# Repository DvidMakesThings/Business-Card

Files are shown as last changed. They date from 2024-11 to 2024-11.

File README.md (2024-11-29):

# Business_Card_LA Project

Business_Card_LA is a unique project where a business card doubles as a logic analyzer. It is designed based on Cypress CY7C68013A USB controller. It can sample 8 channels at the same time. The maximum sampling rate of each channel is 24Mhz, and the maximum logical level supports 5.5V. The software adopts sigrok-PulseView, which is open source, and supports Linux, Windows, Mac OS X and other platforms. It supports more than 100 kinds of protocol analysis, and can add its own protocol analysis.

## Specifications
- **Sampling rate and number of channels**: 24Mhz, 8 Channel
- **Signal input range**: 0-5.5V
- **High and low level recognition range**: Vin High: >2V, Vin Low: <0.8V
- **Communication mode**: USB 2.0 (In order to ensure the sampling rate of 24Mhz, try not to use USB docking station)

## Usage
1. **Download sigrok-PulseView Software**: Be sure to download the Release build from [sigrok Downloads](https://sigrok.org/wiki/Downloads).
2. **Install sigrok-PulseView & LogicAnalyzer driver**:
   - After PulseView is installed, run Zadig from the installation folder: `\sigrok\PulseView\zadig.exe`.
   - Select the device you want to install the driver on. The business card appears as Unknown device with VID/PID 04B4:8613.
   - Check Edit, change the device name to fx2LAFw, and then click Install Driver.
3. **Run PulseView**:
   - Click PulseView to run the software.
   - The status LED will light up and it's blue, indicating that the firmware is loaded successfully and the logic signal can be sampled.

## Supported Protocols
See [sigrok Supported Protocol decoders](https://sigrok.org/wiki/Protocol_decoders).

## License
This project is licensed under the GPL-3.0 License.

## Contact
For any questions or feedback, please contact:
- Email: [s.dvid@hotmail.com](mailto:s.dvid@hotmail.com)
- GitHub: [DvidMakesThings](https://github.com/DvidMakesThings)

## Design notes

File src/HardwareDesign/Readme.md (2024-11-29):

# # Business_Card_LA Project Hardware Design Files

## Contents
This folder contains the hardware design files for the Business_Card_LA project. The main components include:
- Schematic diagrams
- PCB layouts
- Bill of Materials (BOM)
- Gerber files

## Usage
To use these hardware design files:
1. Open the schematic diagrams and PCB layouts using EAGLE software.
2. Review the Bill of Materials for required components.
3. Follow the design files to assemble and test the hardware.
4. Use the Gerber files for PCB manufacturing.

## License
This project is licensed under the MIT License.

## Contact
For any questions or feedback, please contact:
- Email: [s.dvid@hotmail.com](mailto:s.dvid@hotmail.com)
- GitHub: [DvidMakesThings](https://github.com/DvidMakesThings)

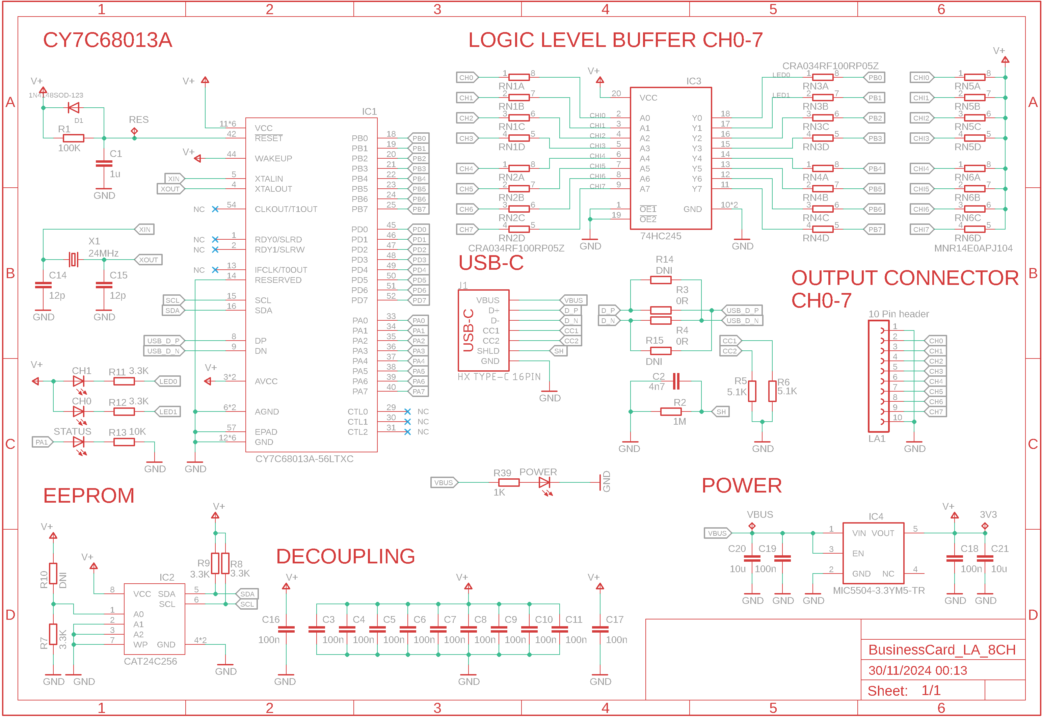
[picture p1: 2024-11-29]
images/schematics.png

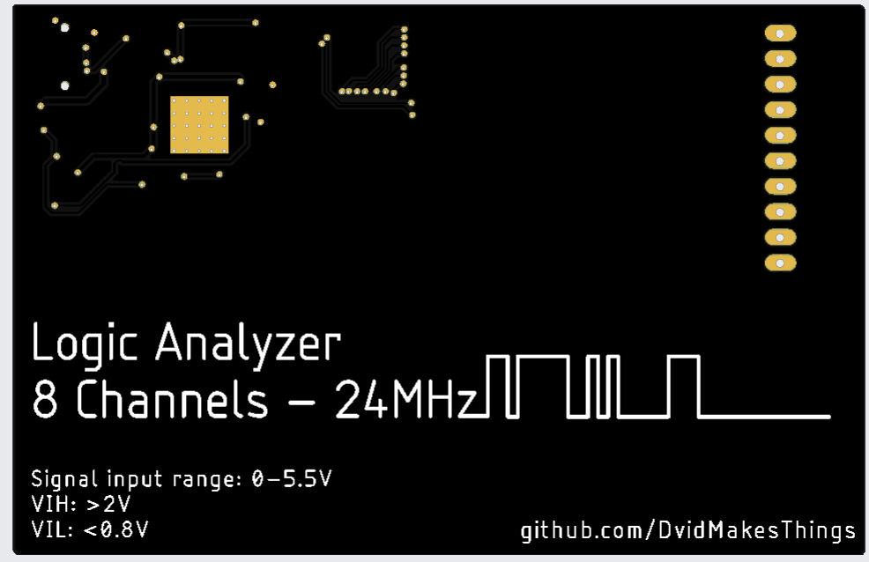
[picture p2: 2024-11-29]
images/PCB_Bottom.png

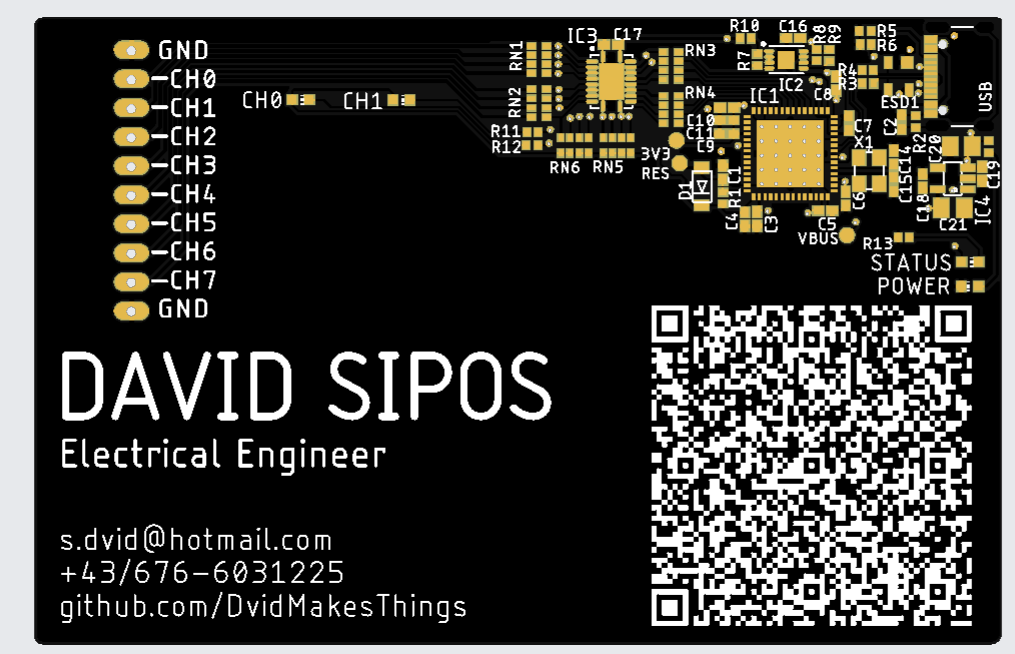
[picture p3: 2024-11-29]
images/PCB_Top.png

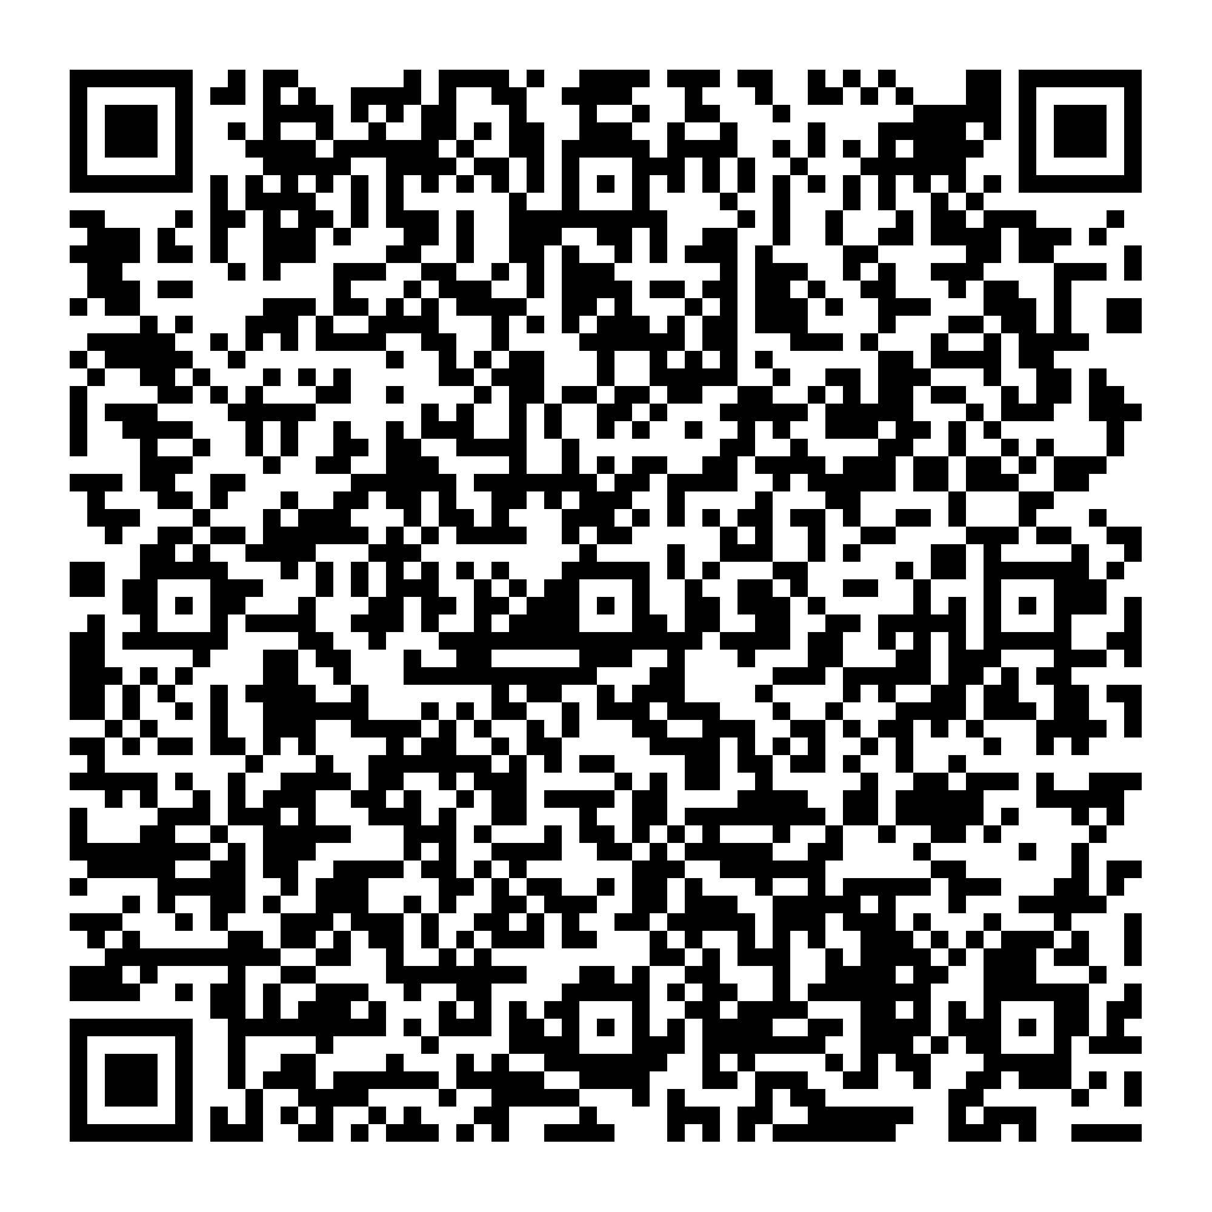
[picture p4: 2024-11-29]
images/qr_vcard.png

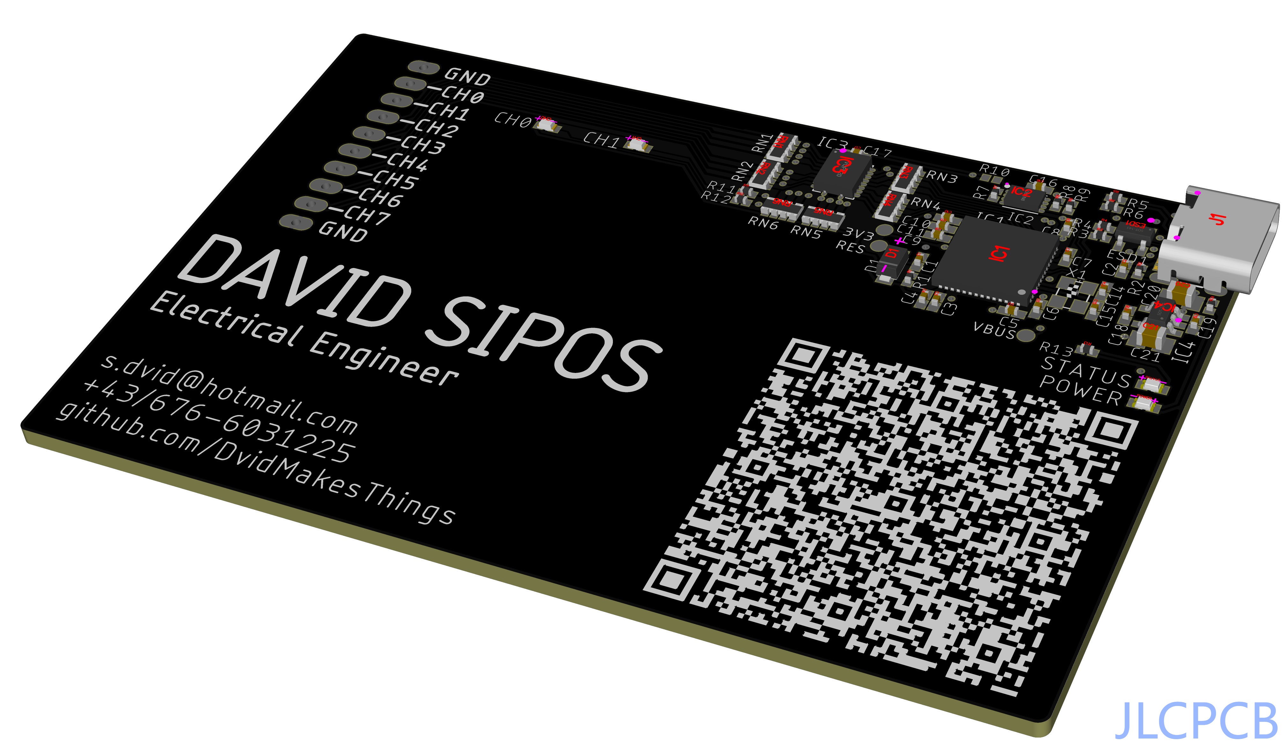
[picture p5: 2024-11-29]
images/capture-2024-11-15T15_52_39.032Z.jpg

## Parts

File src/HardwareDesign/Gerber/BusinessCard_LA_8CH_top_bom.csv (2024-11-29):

Comment | Designator | Footprint | LCSC Part #
 | POWER | CHIP-LED0603
0R | R3 R4 | R0402
1K | R39 | R0402
1M | R2 | R0402
1N4148SOD-123 | D1 | SOD-123FL
1u | C1 | C0402K
3.3K | R7 R8 R9 R11 R12 | R0402
4n7 | C2 | C0402K
5.1K | R5 R6 | R0402
10K | R13 | R0402
10u | C20 C21 | C0805K
12p | C14 C15 | C0402K
19-217/GHC-YR1S2/3T | CH0 CH1 | CHIP-LED0603
24MHz | X1 | 3.2X2.5_KX-7
100K | R1 | R0402
100n | C3 C4 C5 C6 C7 C8 C9 C10 C11 C16 C17 C18 C19 | C0402K
CAT24C256HU4IGT3 | IC2 | SON50P300X200X50-9T130X140N
CRA034RF100RP05Z | RN1 RN2 RN3 RN4 | CAT16
CY7C68013A-56LTXC | IC1 | QFN50P800X800X100-57T665
DNI | R10 | R0402
HX TYPE-C 16PIN | J1 | USB-C-16P-2LAYER-PADS
MIC5504-3.3YM5-TR | IC4 | SOT23-5
MNR14E0APJ104 | RN5 RN6 | CAT16
SN74LVC541ARGYR | IC3 | QFN50P350X450X100-25T305X205N
TPB1 27 | 3V3 | B1 27
TPB1 27 | RES | B1 27
TPB1 27 | VBUS | B1 27
YLED0603B | STATUS | CHIP-LED0603

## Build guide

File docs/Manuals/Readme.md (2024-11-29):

# Business_Card_LA Project Manuals

## Contents
- Manuals

## Usage
This folder contains documentation and manuals for the Business_Card_LA project.

## License
This project is licensed under the MIT License.

## Contact
For any questions or feedback, please contact:
- Email: [s.dvid@hotmail.com](mailto:s.dvid@hotmail.com)
- GitHub: [DvidMakesThings](https://github.com/DvidMakesThings)

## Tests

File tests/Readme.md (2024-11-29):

# Business_Card_LA Project Test files

This folder contains the main test files for the Business_Card_LA project.

## Contents
- Various test scripts and files for the Business_Card_LA project.

## Usage
1. Clone the repository.
2. Navigate to this folder.
3. Run the test scripts as needed.

## License
This project is licensed under the MIT License.

## Contact
For any questions or feedback, please contact:
- Email: [s.dvid@hotmail.com](mailto:s.dvid@hotmail.com)
- GitHub: [DvidMakesThings](https://github.com/DvidMakesThings)

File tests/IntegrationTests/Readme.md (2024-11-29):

# # Business_Card_LA Project Integration Tests

This folder contains integration tests for the Business_Card_LA project.

## Contents

- Various integration test scripts and resources.

## Usage

1. Clone the repository.
2. Navigate to this folder.
3. Run the integration tests using your preferred testing framework.

## License
This project is licensed under the MIT License.

## Contact
For any questions or feedback, please contact:
- Email: [s.dvid@hotmail.com](mailto:s.dvid@hotmail.com)
- GitHub: [DvidMakesThings](https://github.com/DvidMakesThings)

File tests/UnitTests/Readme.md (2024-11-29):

# Business_Card_LA Project Unit Tests

## Contents
This folder contains unit tests for the Business_Card_LA project.

## Usage
To run the unit tests, navigate to this directory and execute the test scripts using your preferred testing framework.

## License
This project is licensed under the MIT License.

## Contact
For any questions or feedback, please contact:
- Email: [s.dvid@hotmail.com](mailto:s.dvid@hotmail.com)
- GitHub: [DvidMakesThings](https://github.com/DvidMakesThings)

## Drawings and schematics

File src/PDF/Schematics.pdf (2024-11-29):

# CY7C68013A

# LOGIC LEVEL BUFFER CH0-7

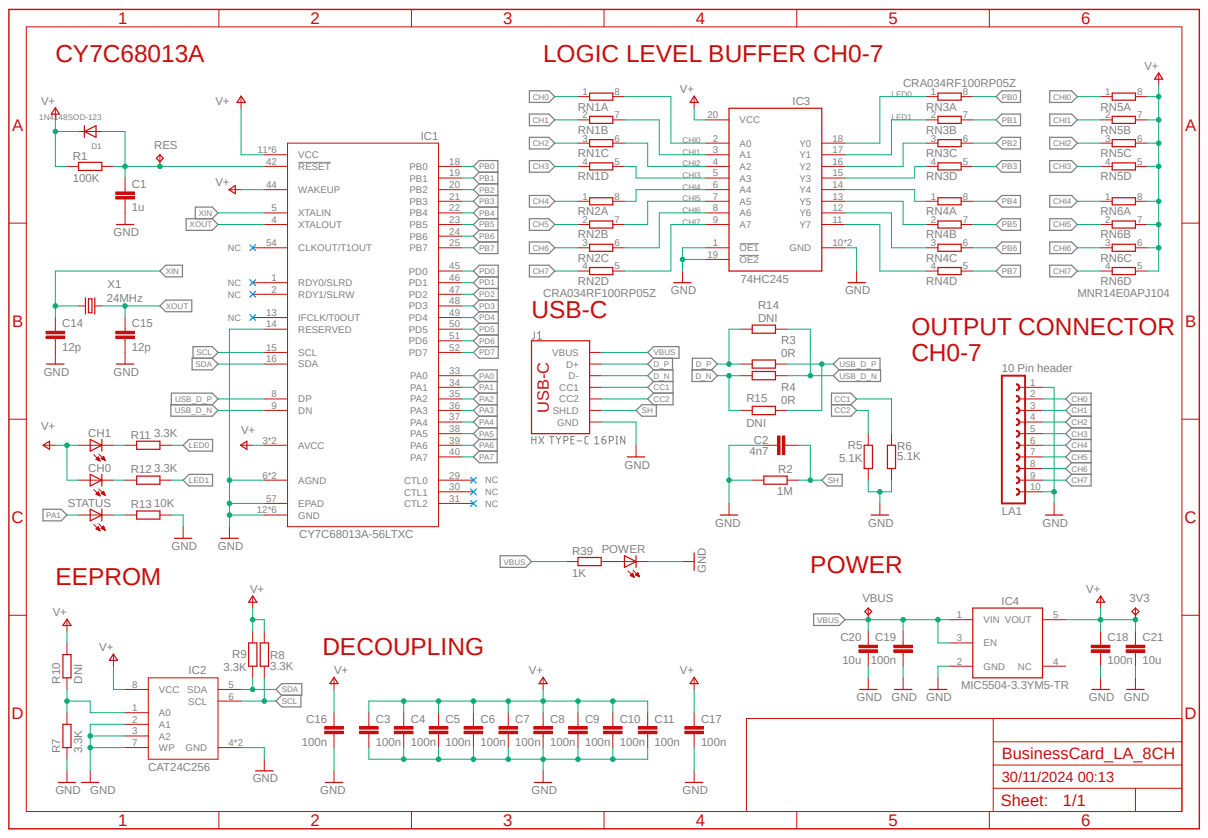
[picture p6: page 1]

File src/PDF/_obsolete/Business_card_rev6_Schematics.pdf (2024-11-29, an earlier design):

A

A

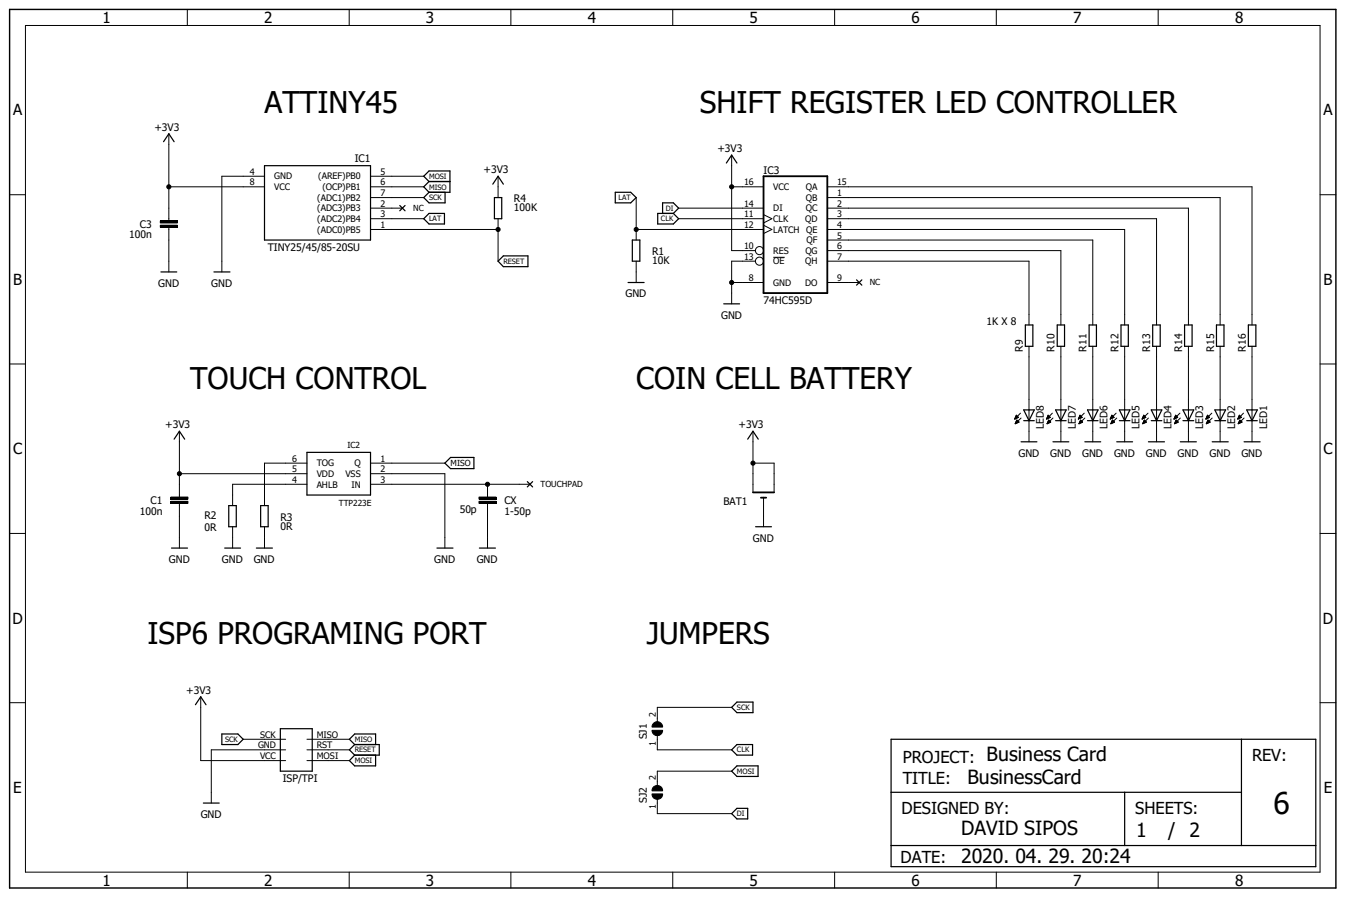
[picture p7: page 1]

SHIFT REGISTER LED CONTROLLER

GND GND GND GND

Business Card PROJECT: BusinessCard TITLE: | REV:

DESIGNED BY: DAVID SIPOS | SHEETS: 1 2 /

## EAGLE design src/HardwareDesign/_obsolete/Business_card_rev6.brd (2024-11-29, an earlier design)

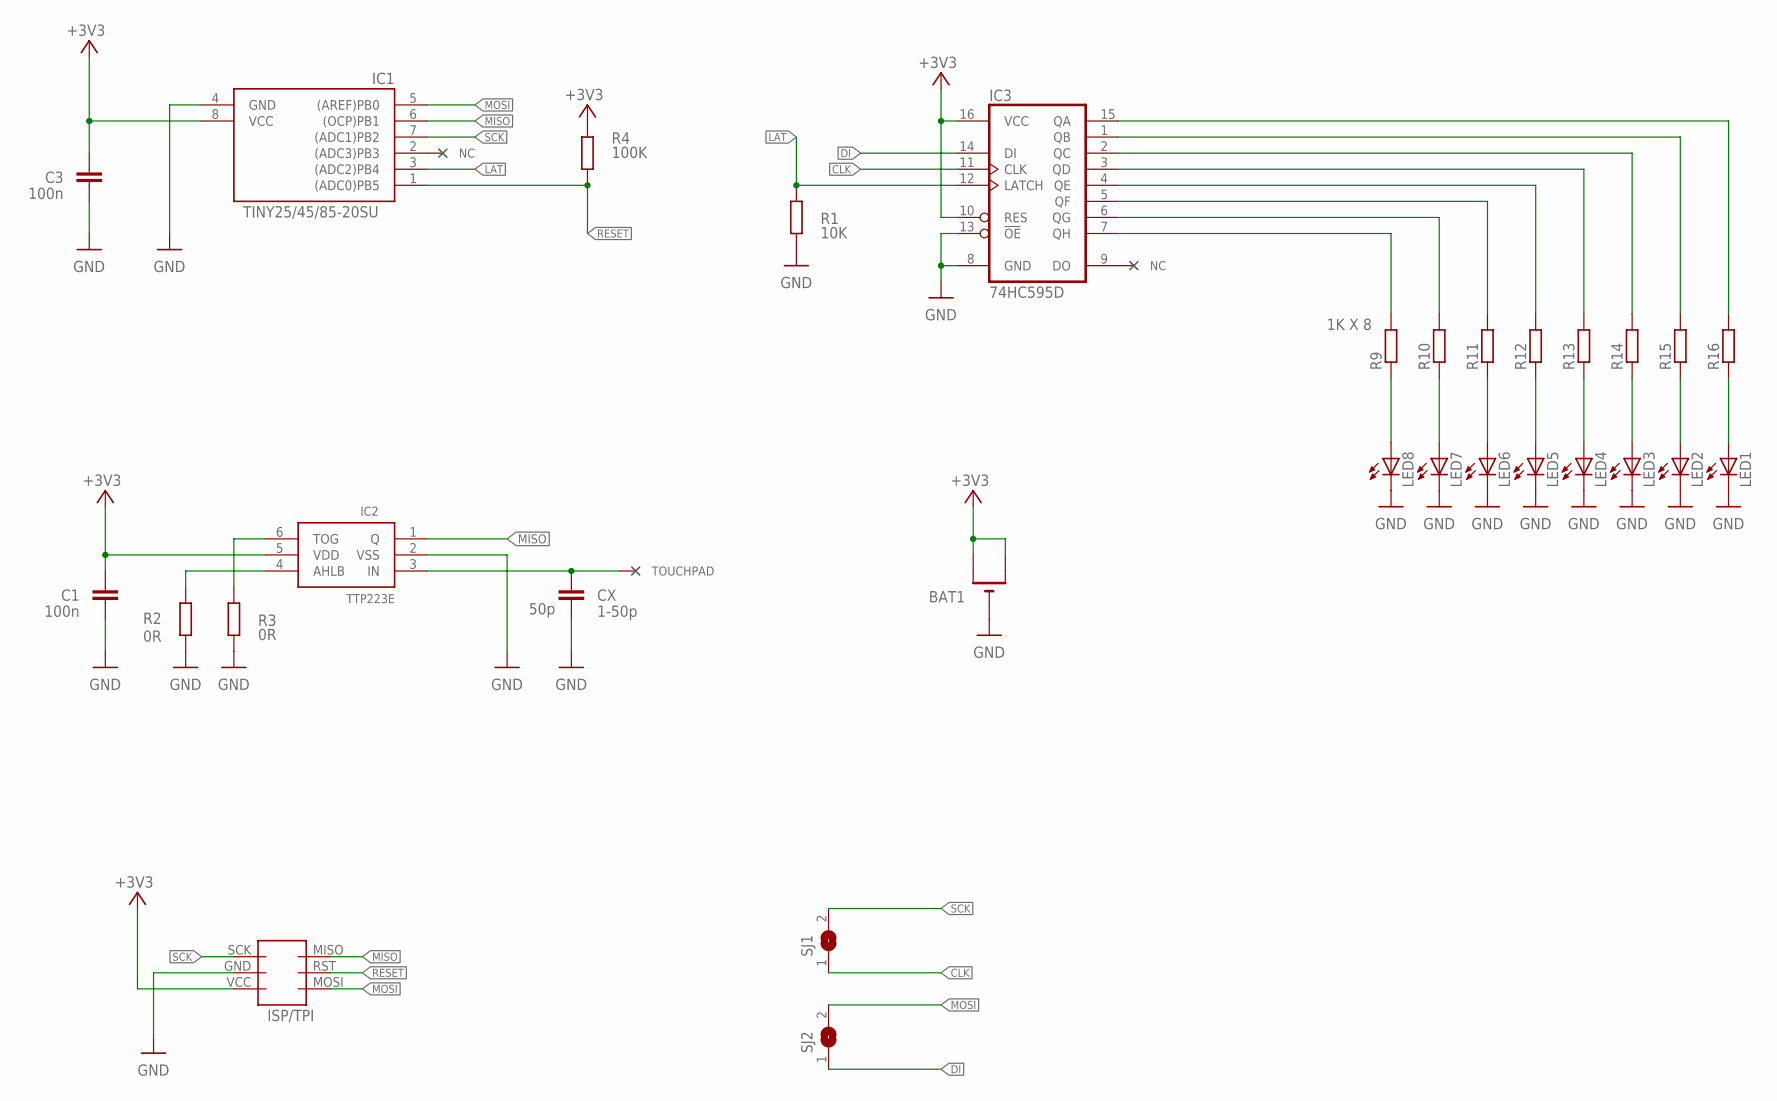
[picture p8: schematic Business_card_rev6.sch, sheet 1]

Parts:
BAT1: CR2032SMT; CR2032-SMD
C1, C3: 100n; C1206K
CX: 1-50p; C1206K
IC1: TINY25/45/85-20SU; SOIC8
IC2: TTP223E; SOT23-6
IC3: 74HC595D; SO16
LED1, LED2, LED3, LED4, LED5, LED6, LED7, LED8: LEDCHIPLED_0805; CHIPLED_0805
R1: 10K; M0805
R2, R3: 0R; M0805
R4: 100K; M0805
R9, R10, R11, R12, R13, R14, R15, R16: R-EU_M0805; M0805
SJ1, SJ2: SJ
U$11: AVR-ISP-6-EDGE; 6PAD_ISP

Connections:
+3V3: BAT1.+$1 (+), BAT1.+$2 (+1), C1.2, C3.2, IC1.8 (VCC), IC2.5 (VDD), IC3.10 (RES), IC3.16 (VCC), R4.2, U$11.VCC; also elsewhere on the board
CAPSEN: CX.2, IC2.3 (IN)
CLK: IC3.11 (CLK), SJ1.1
DI: IC3.14 (DI), SJ2.1
GND: BAT1.-, C1.1, C3.1, CX.1, IC1.4 (GND), IC2.2 (VSS), IC3.8 (GND), IC3.13 (!OE), LED1.C, LED2.C, LED3.C, LED4.C, LED5.C, LED6.C, LED7.C, LED8.C, R1.2, R2.1, R3.1, U$11.GND; also elsewhere on the board
LAT: IC1.3 ((ADC2)PB4), IC3.12 (LATCH), R1.1
MISO: IC1.6 ((OCP)PB1), IC2.1 (Q), U$11.MISO
MOSI: IC1.5 ((AREF)PB0), SJ2.2, U$11.MOSI
unnamed: IC3.15 (QA), R16.2
unnamed: IC3.1 (QB), R15.2
unnamed: IC2.6 (TOG), R3.2
unnamed: IC2.4 (AHLB), R2.2
unnamed: IC3.2 (QC), R14.2
unnamed: IC3.3 (QD), R13.2
unnamed: IC3.4 (QE), R12.2
unnamed: IC3.5 (QF), R11.2
unnamed: IC3.6 (QG), R10.2
unnamed: IC3.7 (QH), R9.2
unnamed: LED8.A, R9.1
unnamed: LED7.A, R10.1
unnamed: LED6.A, R11.1
unnamed: LED5.A, R12.1
unnamed: LED4.A, R13.1
unnamed: LED3.A, R14.1
unnamed: LED2.A, R15.1
unnamed: LED1.A, R16.1
RESET: IC1.1 ((ADC0)PB5), R4.1, U$11.RST
SCK: IC1.7 ((ADC1)PB2), SJ1.2, U$11.SCK

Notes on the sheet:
50p
TOUCHPAD
IC2
TTP223E
1K X 8

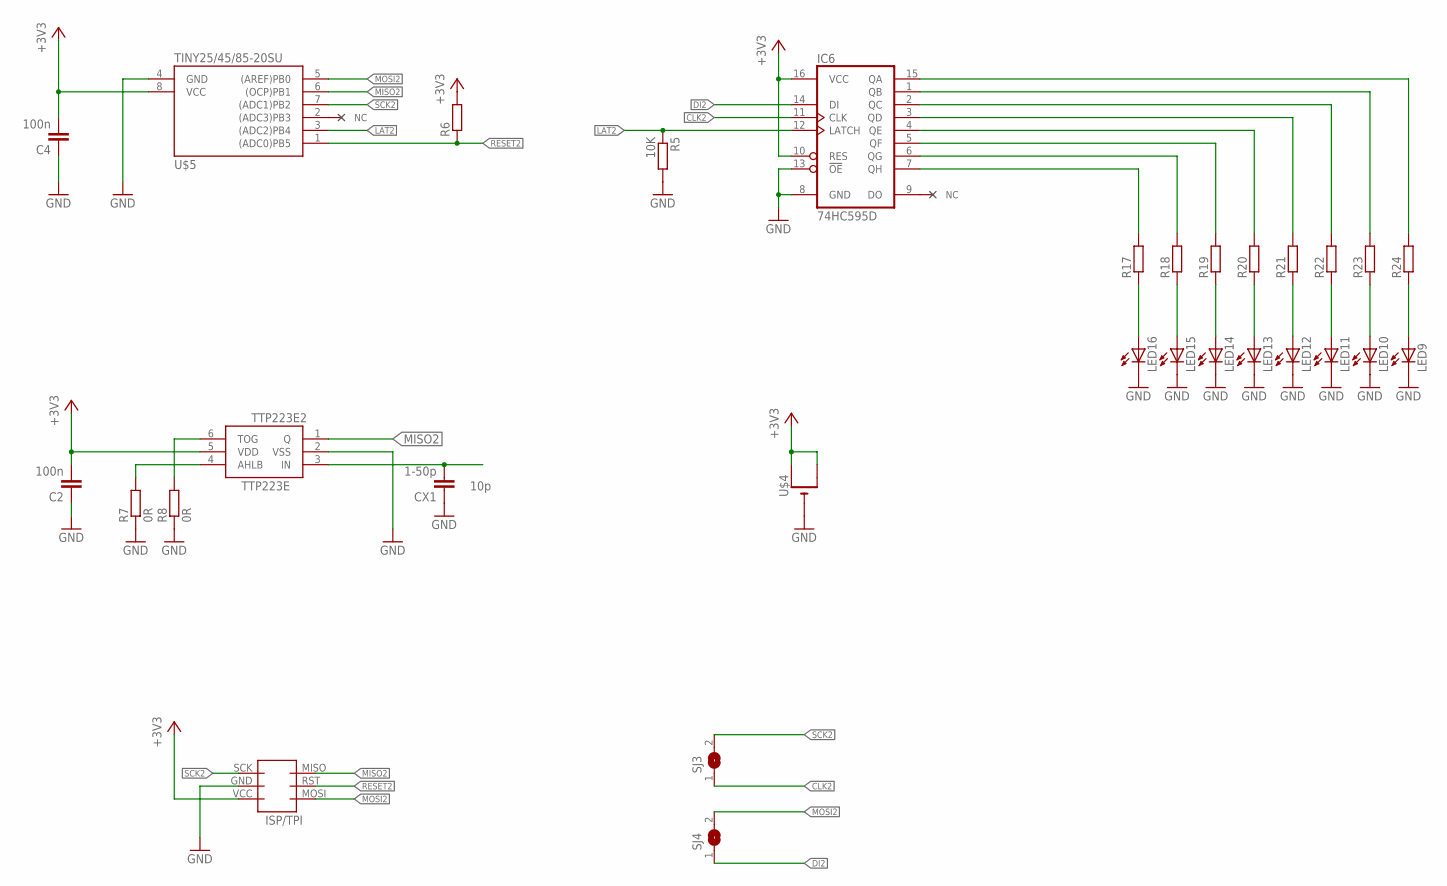
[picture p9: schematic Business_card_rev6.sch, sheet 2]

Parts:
C2, C4: 100n; C1206K
CX1: 1-50p; C1206K
IC6: 74HC595D; SO16
LED9, LED10, LED11, LED12, LED13, LED14, LED15, LED16: LEDCHIPLED_0805; CHIPLED_0805
R5: 10K; M0805
R6, R17, R18, R19, R20, R21, R22, R23, R24: R-EU_M0805; M0805
R7, R8: 0R; M0805
SJ3, SJ4: SJ
TTP223E2: TTP223E; SOT23-6
U$4: CR2032SMT; CR2032-SMD
U$5: TINY25/45/85-20SU; SOIC8
U$12: AVR-ISP-6-EDGE; 6PAD_ISP

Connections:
+3V3: C2.2, C4.2, IC6.10 (RES), IC6.16 (VCC), R6.2, TTP223E2.5 (VDD), U$4.+$1 (+), U$4.+$2 (+1), U$5.8 (VCC), U$12.VCC; also elsewhere on the board
CAPSEN1: CX1.2, TTP223E2.3 (IN)
CLK2: IC6.11 (CLK), SJ3.1
DI2: IC6.14 (DI), SJ4.1
GND: C2.1, C4.1, CX1.1, IC6.8 (GND), IC6.13 (!OE), LED9.C, LED10.C, LED11.C, LED12.C, LED13.C, LED14.C, LED15.C, LED16.C, R5.2, R7.1, R8.1, TTP223E2.2 (VSS), U$4.-, U$5.4 (GND), U$12.GND; also elsewhere on the board
LAT2: IC6.12 (LATCH), R5.1, U$5.3 ((ADC2)PB4)
MISO2: TTP223E2.1 (Q), U$5.6 ((OCP)PB1), U$12.MISO
MOSI2: SJ4.2, U$5.5 ((AREF)PB0), U$12.MOSI
unnamed: R8.2, TTP223E2.6 (TOG)
unnamed: R7.2, TTP223E2.4 (AHLB)
unnamed: IC6.15 (QA), R24.2
unnamed: IC6.1 (QB), R23.2
unnamed: IC6.2 (QC), R22.2
unnamed: IC6.3 (QD), R21.2
unnamed: IC6.4 (QE), R20.2
unnamed: IC6.5 (QF), R19.2
unnamed: IC6.6 (QG), R18.2
unnamed: IC6.7 (QH), R17.2
unnamed: LED16.A, R17.1
unnamed: LED15.A, R18.1
unnamed: LED14.A, R19.1
unnamed: LED13.A, R20.1
unnamed: LED12.A, R21.1
unnamed: LED11.A, R22.1
unnamed: LED10.A, R23.1
unnamed: LED9.A, R24.1
RESET2: R6.1, U$5.1 ((ADC0)PB5), U$12.RST
SCK2: SJ3.2, U$5.7 ((ADC1)PB2), U$12.SCK

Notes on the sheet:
10p

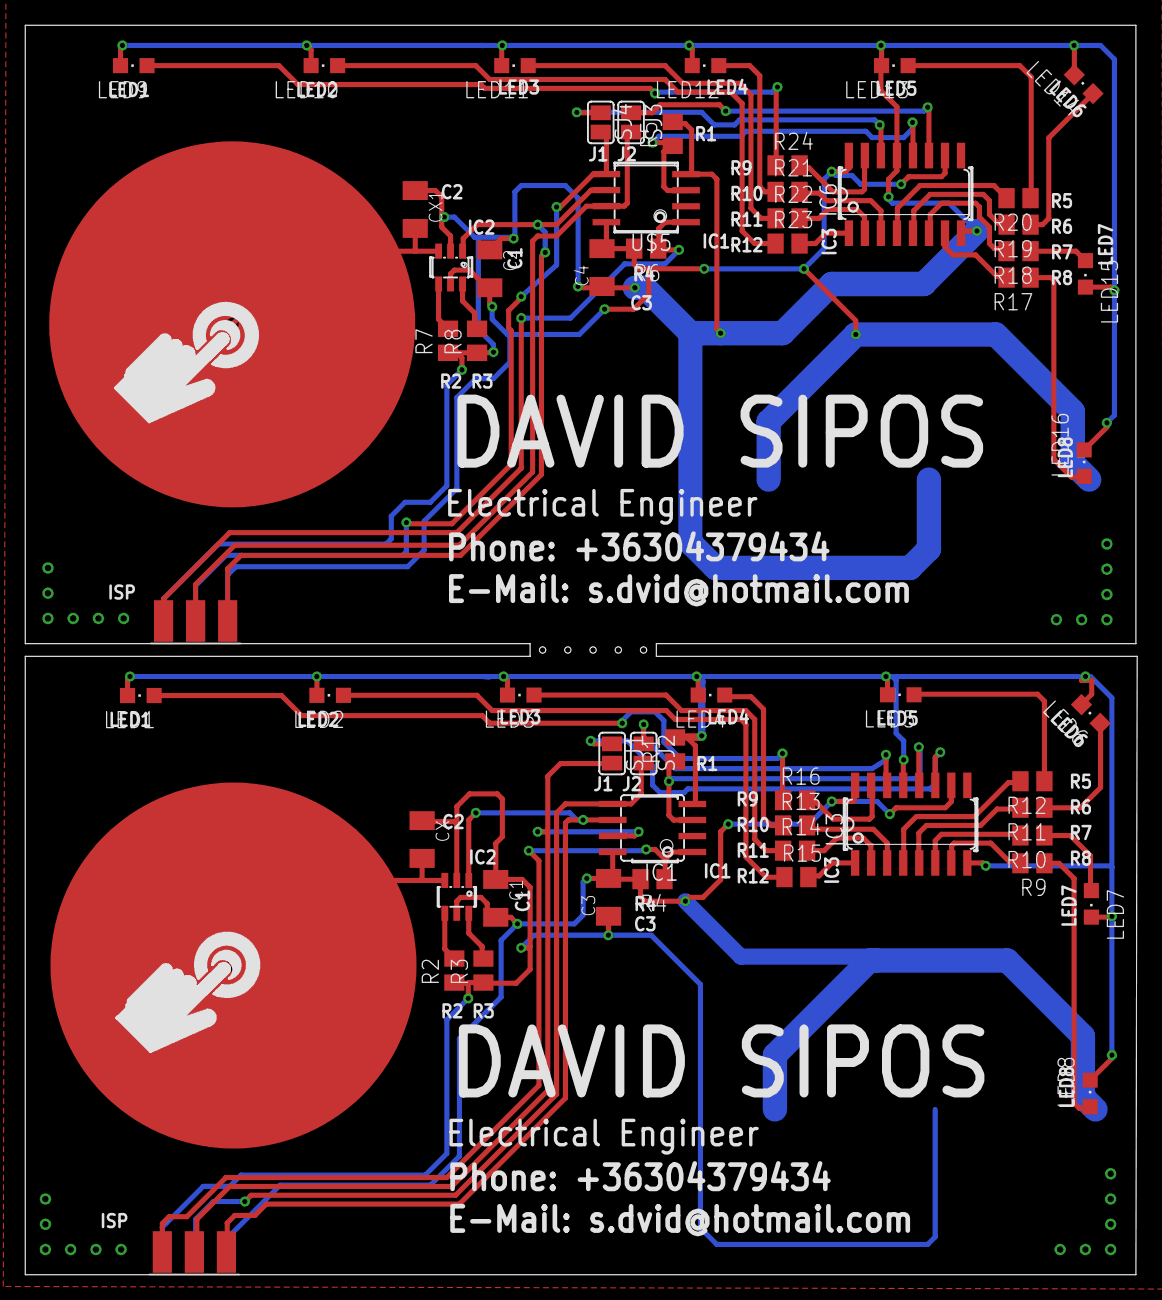
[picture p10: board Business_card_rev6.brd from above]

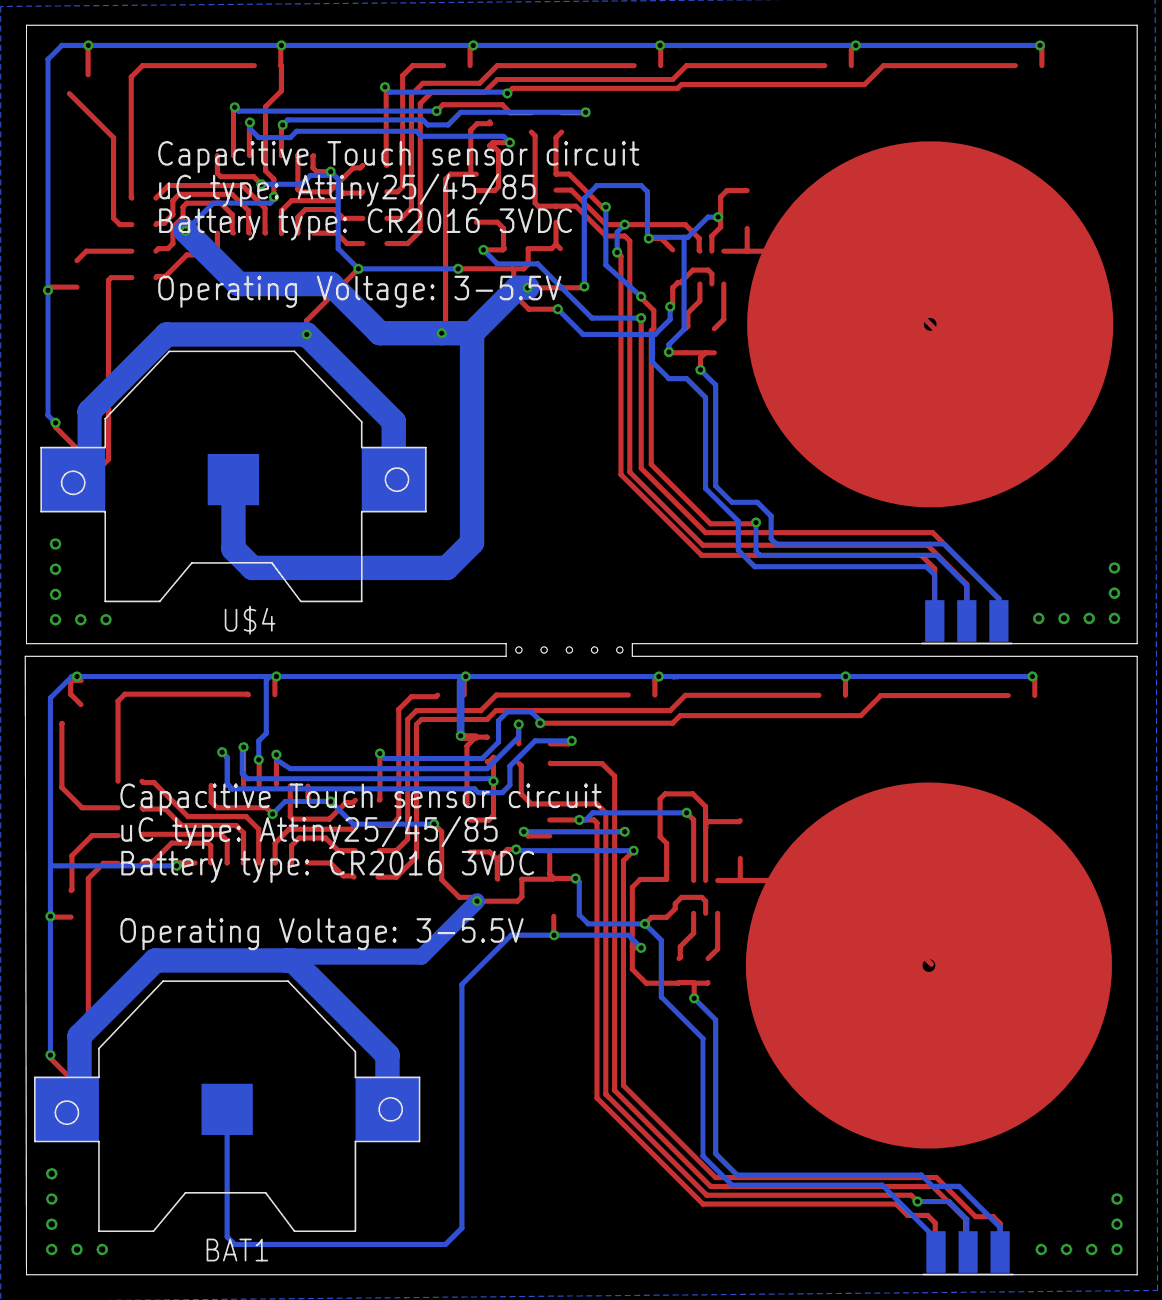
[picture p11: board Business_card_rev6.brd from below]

Board: 2 copper layers, 88.1 x 99.0 mm, 60 parts (2 on the bottom side), 54 nets.

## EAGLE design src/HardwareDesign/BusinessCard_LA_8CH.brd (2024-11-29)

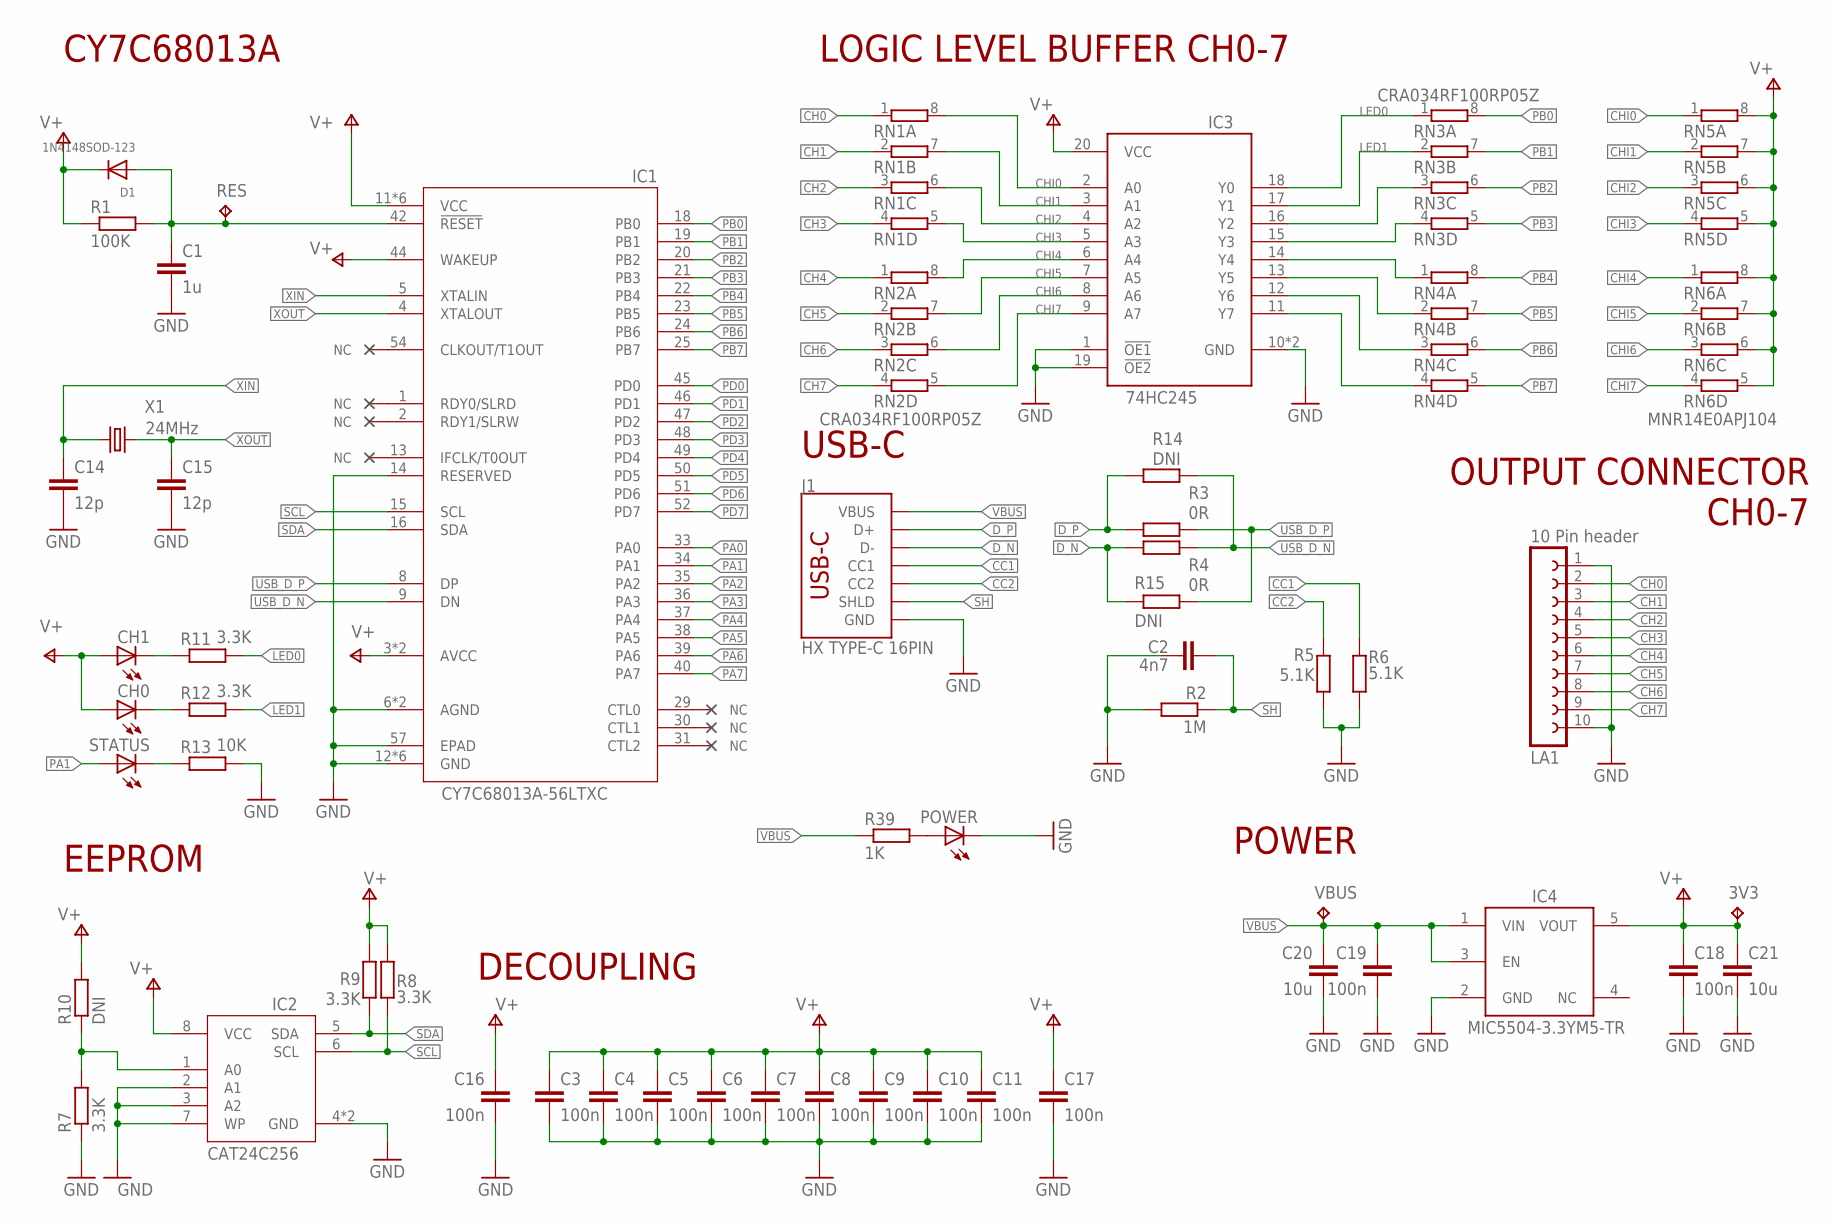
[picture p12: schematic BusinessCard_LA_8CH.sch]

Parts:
3V3: TPB1,27; B1,27
C1: 1u; C0402K
C2: 4n7; C0402K
C3, C4, C5, C6, C7, C8, C9, C10, C11, C16, C17, C18, C19: 100n; C0402K
C14, C15: 12p; C0402K
C20, C21: 10u; C0805K
CH0, CH1: 19-217/GHC-YR1S2/3T; CHIP-LED0603
D1: 1N4148SOD-123; SOD-123FL
IC1: CY7C68013A-56LTXC; QFN50P800X800X100-57T665
IC2: CAT24C256HU4IGT3; SON50P300X200X50-9T130X140N
IC3: SN74LVC541ARGYR; QFN50P350X450X100-25T305X205N
IC4: MIC5504-3.3YM5-TR; SOT23-5
J1: HX TYPE-C 16PIN; USB-C-16P-2LAYER-PADS
LA1: 10 Pin header; FE10
POWER: 19-213/Y2C-CQ2R2L/3T(CY); CHIP-LED0603
R1: 100K; R0402
R2: 1M; R0402
R3, R4: 0R; R0402
R5, R6: 5.1K; R0402
R7, R8, R9, R11, R12: 3.3K; R0402
R10, R14, R15: DNI; R0402
R13: 10K; R0402
R39: 1K; R0402
RES: TPB1,27; B1,27
RN1, RN2, RN3, RN4: CRA034RF100RP05Z; CAT16
RN5, RN6: MNR14E0APJ104; CAT16
STATUS: YLED0603B; CHIP-LED0603
VBUS: TPB1,27; B1,27
X1: 24MHz; 3.2X2.5_KX-7

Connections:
CC1: J1.A5 (CC1), R6.1
CC2: J1.B5 (CC2), R5.1
CH0: LA1.2, RN1.1
CH1: LA1.3, RN1.2 (1)
CH2: LA1.4, RN1.3 (1)
CH3: LA1.5, RN1.4 (1)
CH4: LA1.6, RN2.1
CH5: LA1.7, RN2.2 (1)
CH6: LA1.8, RN2.3 (1)
CH7: LA1.9, RN2.4 (1)
CHI0: IC3.2 (A0), RN1.8 (2), RN5.1
CHI1: IC3.3 (A1), RN1.7 (2), RN5.2 (1)
CHI2: IC3.4 (A2), RN1.6 (2), RN5.3 (1)
CHI3: IC3.5 (A3), RN1.5 (2), RN5.4 (1)
CHI4: IC3.6 (A4), RN2.8 (2), RN6.1
CHI5: IC3.7 (A5), RN2.7 (2), RN6.2 (1)
CHI6: IC3.8 (A6), RN2.6 (2), RN6.3 (1)
CHI7: IC3.9 (A7), RN2.5 (2), RN6.4 (1)
D_N: J1.A7 (D-), J1.B7 (D-), R4.2, R15.2
D_P: J1.A6 (D+), J1.B6 (D+), R3.2, R14.2
GND: C1.2, C2.2, C3.2, C4.2, C5.2, C6.2, C7.2, C8.2, C9.2, C10.2, C11.2, C14.2, C15.2, C16.2, C17.2, C18.2, C19.2, C20.2, C21.2, IC1.6 (AGND), IC1.10 (AGND), IC1.12 (GND), IC1.14 (RESERVED), IC1.26 (GND), IC1.28 (GND), IC1.41 (GND), IC1.53 (GND), IC1.56 (GND), IC1.57 (EPAD), IC2.2 (A1), IC2.3 (A2), IC2.4 (GND), IC2.7 (WP), IC2.9 (GND), IC3.1 (!OE1), IC3.10 (GND), IC3.19 (!OE2), IC3.PAD (GND), IC4.2 (GND), J1.GND, J1.GND2 (GND), LA1.1, LA1.10, POWER.C, R2.2, R5.2, R6.2, R7.1, R13.2
LED0: IC3.18 (Y0), R11.2, RN3.1
LED1: IC3.17 (Y1), R12.2, RN3.2 (1)
unnamed: IC2.1 (A0), R7.2, R10.1
unnamed: POWER.A, R39.2
unnamed: C1.1, D1.A, IC1.42 (!RESET), R1.2, RES.TP
unnamed: IC3.16 (Y2), RN3.3 (1)
unnamed: IC3.15 (Y3), RN3.4 (1)
unnamed: IC3.14 (Y4), RN4.1
unnamed: IC3.13 (Y5), RN4.2 (1)
unnamed: IC3.12 (Y6), RN4.3 (1)
unnamed: IC3.11 (Y7), RN4.4 (1)
unnamed: CH1.C, R11.1
unnamed: CH0.C, R12.1
unnamed: R13.1, STATUS.C
PA0: IC1.33 (PA0)
PA1: IC1.34 (PA1), STATUS.A
PA2: IC1.35 (PA2)
PA3: IC1.36 (PA3)
PA4: IC1.37 (PA4)
PA5: IC1.38 (PA5)
PA6: IC1.39 (PA6)
PA7: IC1.40 (PA7)
PB0: IC1.18 (PB0), RN3.8 (2)
PB1: IC1.19 (PB1), RN3.7 (2)
PB2: IC1.20 (PB2), RN3.6 (2)
PB3: IC1.21 (PB3), RN3.5 (2)
PB4: IC1.22 (PB4), RN4.8 (2)
PB5: IC1.23 (PB5), RN4.7 (2)
PB6: IC1.24 (PB6), RN4.6 (2)
PB7: IC1.25 (PB7), RN4.5 (2)
PD0: IC1.45 (PD0)
PD1: IC1.46 (PD1)
PD2: IC1.47 (PD2)
PD3: IC1.48 (PD3)
PD4: IC1.49 (PD4)
PD5: IC1.50 (PD5)
PD6: IC1.51 (PD6)
PD7: IC1.52 (PD7)
SCL: IC1.15 (SCL), IC2.6 (SCL), R8.1
SDA: IC1.16 (SDA), IC2.5 (SDA), R9.1
SH: C2.1, J1.SHLD1 (SHLD), J1.SHLD2 (SHLD), J1.SHLD3 (SHLD), J1.SHLD4 (SHLD), R2.1
USB_D_N: IC1.9 (DN), R4.1, R14.1
USB_D_P: IC1.8 (DP), R3.1, R15.1
V+: 3V3.TP, C3.1, C4.1, C5.1, C6.1, C7.1, C8.1, C9.1, C10.1, C11.1, C16.1, C17.1, C18.1, C21.1, CH0.A, CH1.A, D1.C, IC1.3 (AVCC), IC1.7 (AVCC), IC1.11 (VCC), IC1.17 (VCC), IC1.27 (VCC), IC1.32 (VCC), IC1.43 (VCC), IC1.44 (WAKEUP), IC1.55 (VCC), IC2.8 (VCC), IC3.20 (VCC), IC4.5 (VOUT), R1.1, R8.2, R9.2, R10.2, RN5.5 (2), RN5.6 (2), RN5.7 (2), RN5.8 (2), RN6.5 (2), RN6.6 (2), RN6.7 (2), RN6.8 (2)
VBUS: C19.1, C20.1, IC4.1 (VIN), IC4.3 (EN), J1.VBUS1 (VBUS), J1.VBUS2 (VBUS), R39.1, VBUS.TP
XIN: C14.1, IC1.5 (XTALIN), X1.1
XOUT: C15.1, IC1.4 (XTALOUT), X1.3 (2)

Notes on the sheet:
USB-C
CY7C68013A
EEPROM
OUTPUT CONNECTOR CH0-7
POWER
LOGIC LEVEL BUFFER CH0-7
DECOUPLING

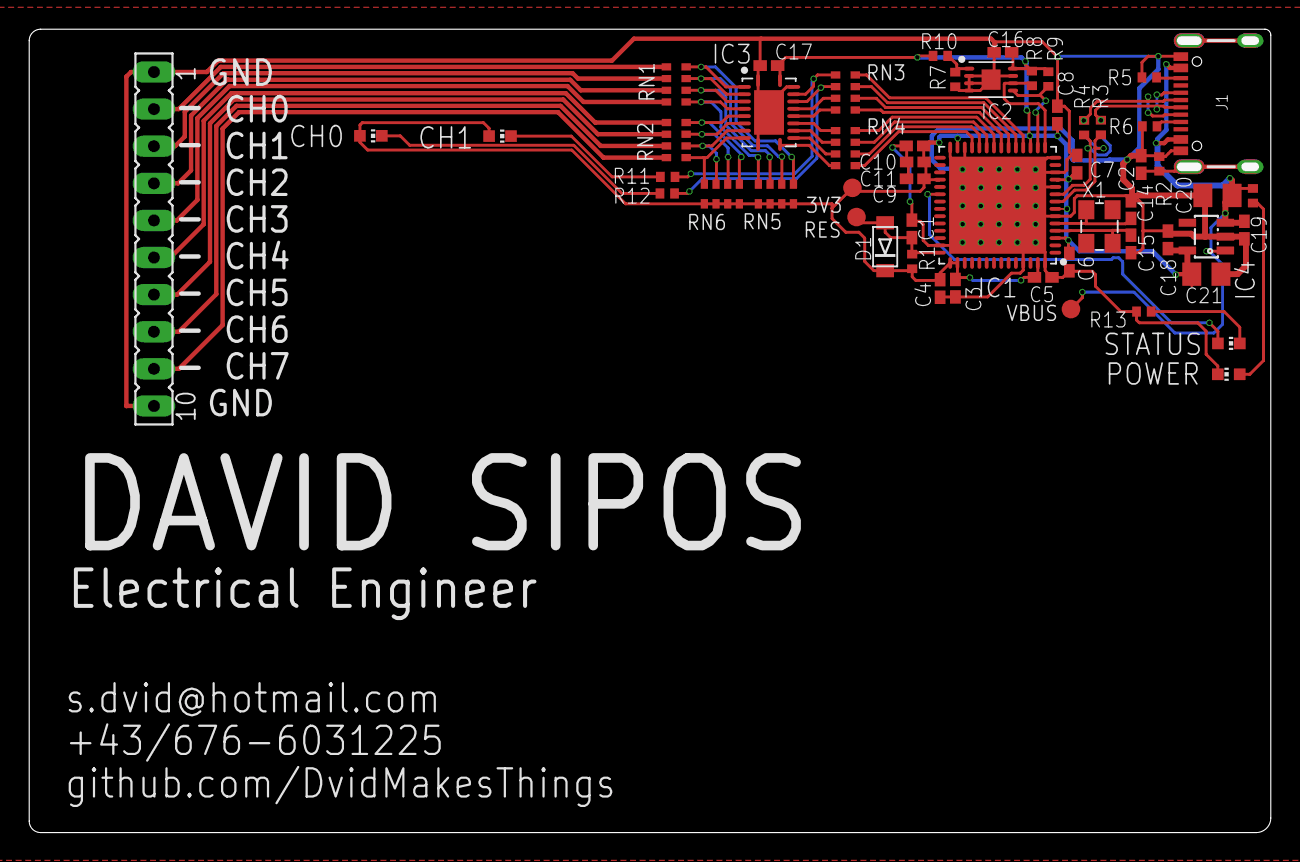
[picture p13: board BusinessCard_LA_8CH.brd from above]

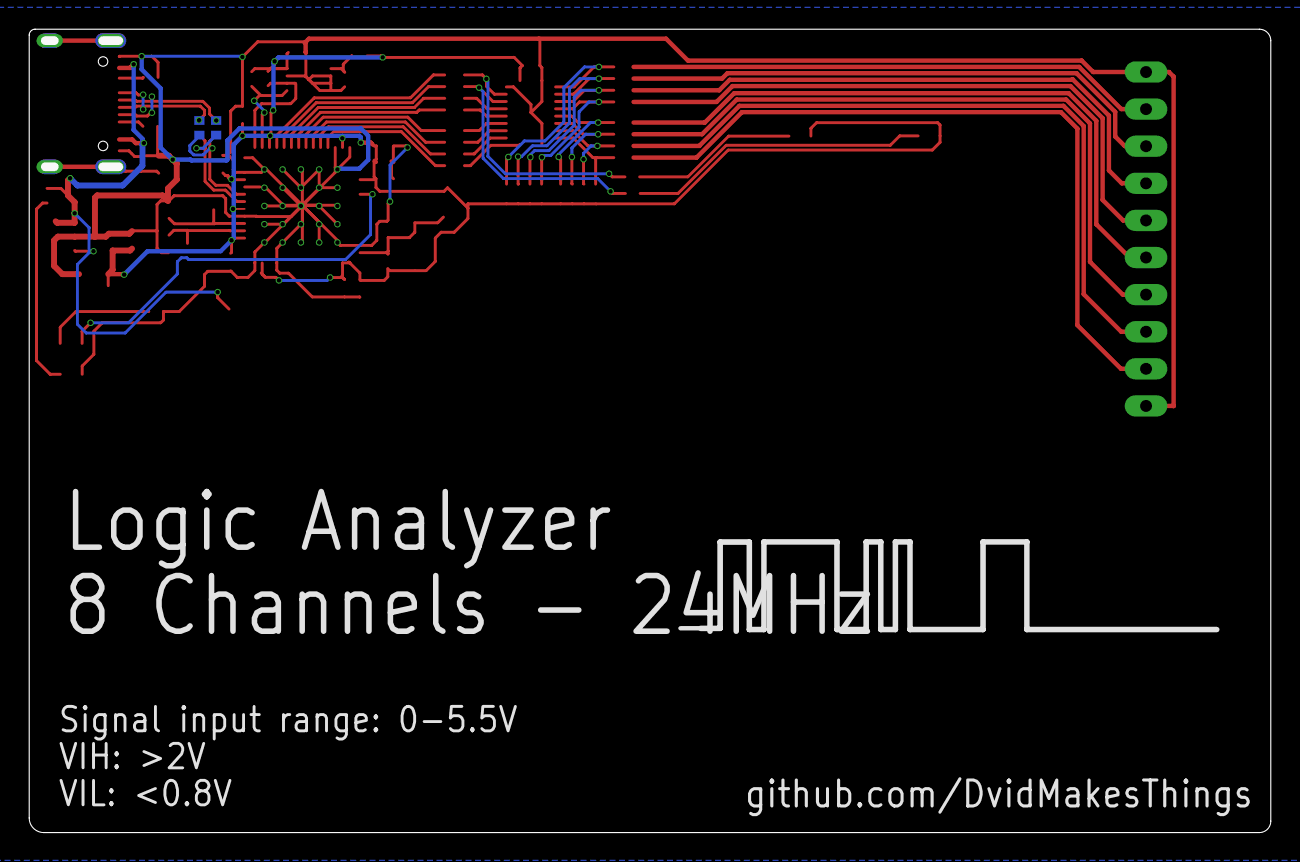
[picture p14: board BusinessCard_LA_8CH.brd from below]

Board: 2 copper layers, 85.0 x 55.0 mm, 56 parts (2 on the bottom side), 53 nets.

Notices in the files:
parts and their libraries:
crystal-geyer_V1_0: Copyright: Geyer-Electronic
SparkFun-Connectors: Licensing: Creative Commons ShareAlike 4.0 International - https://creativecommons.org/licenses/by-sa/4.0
